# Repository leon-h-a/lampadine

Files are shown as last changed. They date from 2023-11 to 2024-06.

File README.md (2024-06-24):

### Connection between Arduino and PCB header
    ARD_13  -> 1
    ARD_12  -> 2
    ARD_11  -> 3
    ARD_10  -> 4
    ARD_GND -> 5

### Settings for programming via Arduino (platformio)
1. Install platformio on Windows
2. Init project ```pio project init --board attiny85``` ($ pio boards)
3. Install dependency ```pio lib install ADCTouch```
4. Setup Platformio to flash via Arduino (platformio.ini)

        [env:attiny85]
        platform = atmelavr
        board = attiny85
        framework = arduino
        upload_protocol = stk500v1
        lib_deps = martin2250/ADCTouch@^1.0.4
        upload_flags =
                -P$UPLOAD_PORT
                -b$UPLOAD_SPEED
        upload_port = COM7
        upload_speed = 19200

5. Flash with ```pio run --target upload```

### In case of avrdude verification error, mismatch byte

Remember to power PCB via USB-C before uploading.

### Timing issues

Define 'board_build.f_cpu' flag in platformio.ini conf file

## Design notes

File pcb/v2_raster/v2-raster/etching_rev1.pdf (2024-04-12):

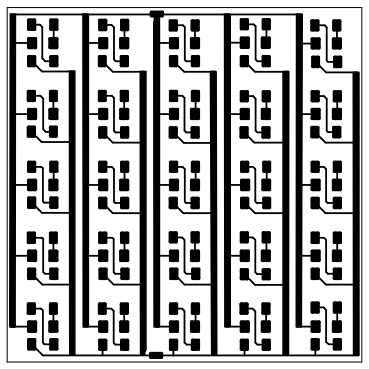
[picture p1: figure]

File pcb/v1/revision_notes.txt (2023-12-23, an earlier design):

V1:
Pogreske kod narucivanja:
2023-12-16 - Assembly V1
 - LED 		krivi footprint (narucene premale)
 - R13 		krivi footprint (naruceni premali)
 - LED10	povecati footprint u schemi
 - C3		krivi footprint (narucen premali)
 - C4		krivi footprint (narucen premali)
 - ARD		povecati footprint THT

Tocke revizije za verziju 2:
* Minimalni footprint za rucno lemljanje 1206(3216 metric)
* Bypass kondenzatore orijentirati jednako (C1 je 'naopacke')
* Drasticno povecati header prema Arduinu i povecati THT vije
* Povecati footprint LED diode koja signalizira napajanje uC-a
* Povecati PAD za External sens zicu
* Pronaci/napraviti footprint USB-C konektora sa THT konaktima (pwr-only)?
* Povecati footprint SRC CAP otpornika (?)

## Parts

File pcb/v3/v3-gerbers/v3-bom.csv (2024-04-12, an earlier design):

Comment | Designator | Footprint | LCSC Part Number
led | D11,D12,D3,D19,D20,D7,D22,D9,D18,D25,D23,D6,D1,D17,D5,D15,D21,D2,D16,D4,D10,D13,D24,D8,D14 | D_0603_1608Metric | C5160732
500 ohm | R19,R24,R22,R12,R6,R27,R20,R18,R11,R29,R10,R28,R25,R26,R16,R21,R7,R17,R14,R5,R23,R9,R15,R13,R8 | R_0603_1608Metric | C2828837
1uF | C1,C2 | C_0603_1608Metric | C1592
0.1uF | C3 | C_0603_1608Metric | C14663
10k | R4,R3 | R_0603_1608Metric | C15401
5k1 | R1,R2 | R_0603_1608Metric | C23186
4.7uF | C4 | C_0603_1608Metric | C1705

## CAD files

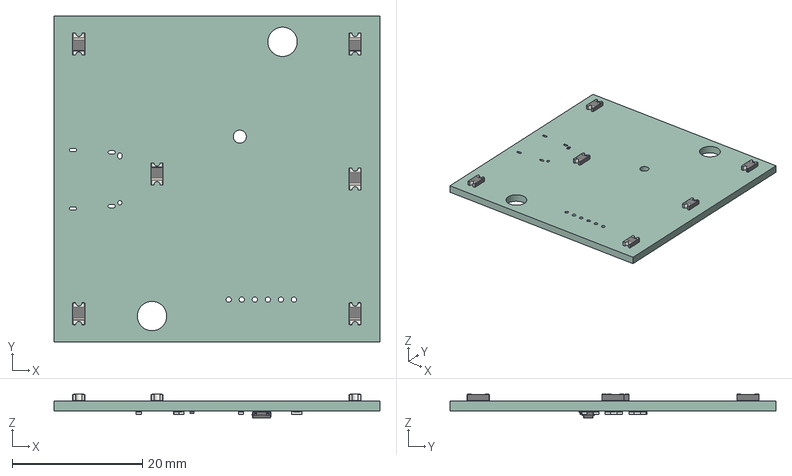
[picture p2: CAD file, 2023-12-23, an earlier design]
pcb/v1/export for inventor/v1-rev1/v1_rev1.step
50.0 x 50.0 x 3.61 mm
v1 PCB

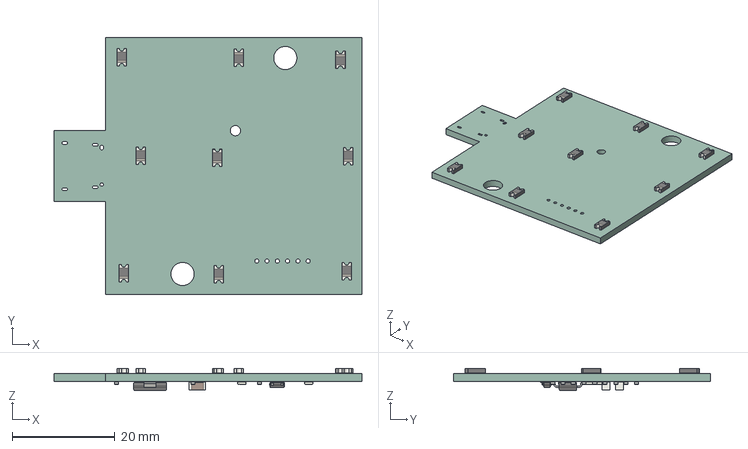
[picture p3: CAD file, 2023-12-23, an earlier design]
pcb/v1/export for inventor/v1-rev2/v1_rev2.step
60.0 x 50.0 x 4.36 mm
v1 PCB

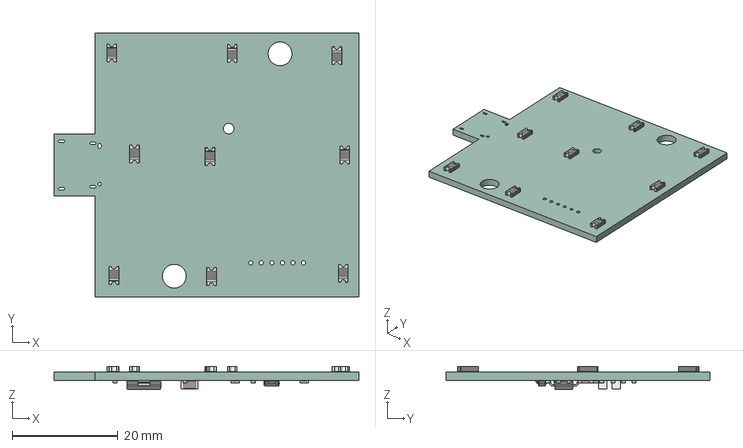
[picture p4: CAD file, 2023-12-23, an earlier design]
pcb/v1/export for inventor/v1-rev3/v1_rev3.step
57.7 x 50.0 x 4.36 mm
_autosave-v1 PCB

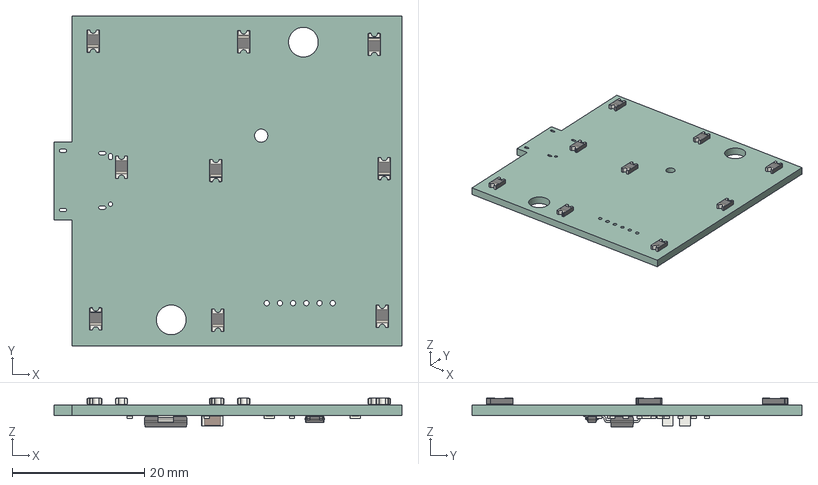
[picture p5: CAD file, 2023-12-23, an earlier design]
pcb/v1/export for inventor/v1-rev4/v1_rev4.step
52.7 x 50.0 x 4.36 mm
v1 PCB

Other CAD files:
pcb/v1/export for inventor/v1-rev1/C_0201_0603Metric.iam
pcb/v1/export for inventor/v1-rev1/D_1206_3216Metric.iam
pcb/v1/export for inventor/v1-rev1/OldVersions/v1_rev1.0003.iam
pcb/v1/export for inventor/v1-rev1/R_0603_1608Metric.iam
pcb/v1/export for inventor/v1-rev1/SOLID.ipt
pcb/v1/export for inventor/v1-rev1/SOLID_1.ipt
pcb/v1/export for inventor/v1-rev1/SOLID_2.ipt
pcb/v1/export for inventor/v1-rev1/SOLID_3.ipt
pcb/v1/export for inventor/v1-rev1/TSOT-23.iam
pcb/v1/export for inventor/v1-rev1/v1 PCB.ipt
pcb/v1/export for inventor/v1-rev1/v1_rev1.iam
pcb/v1/export for inventor/v1-rev2/C_1206_3216Metric.iam
pcb/v1/export for inventor/v1-rev2/D_1206_3216Metric.iam
pcb/v1/export for inventor/v1-rev2/OldVersions/v1_rev2_import.0002.iam
pcb/v1/export for inventor/v1-rev2/R_0603_1608Metric.iam
pcb/v1/export for inventor/v1-rev2/SOLID.ipt
pcb/v1/export for inventor/v1-rev2/SOLID_1.ipt
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

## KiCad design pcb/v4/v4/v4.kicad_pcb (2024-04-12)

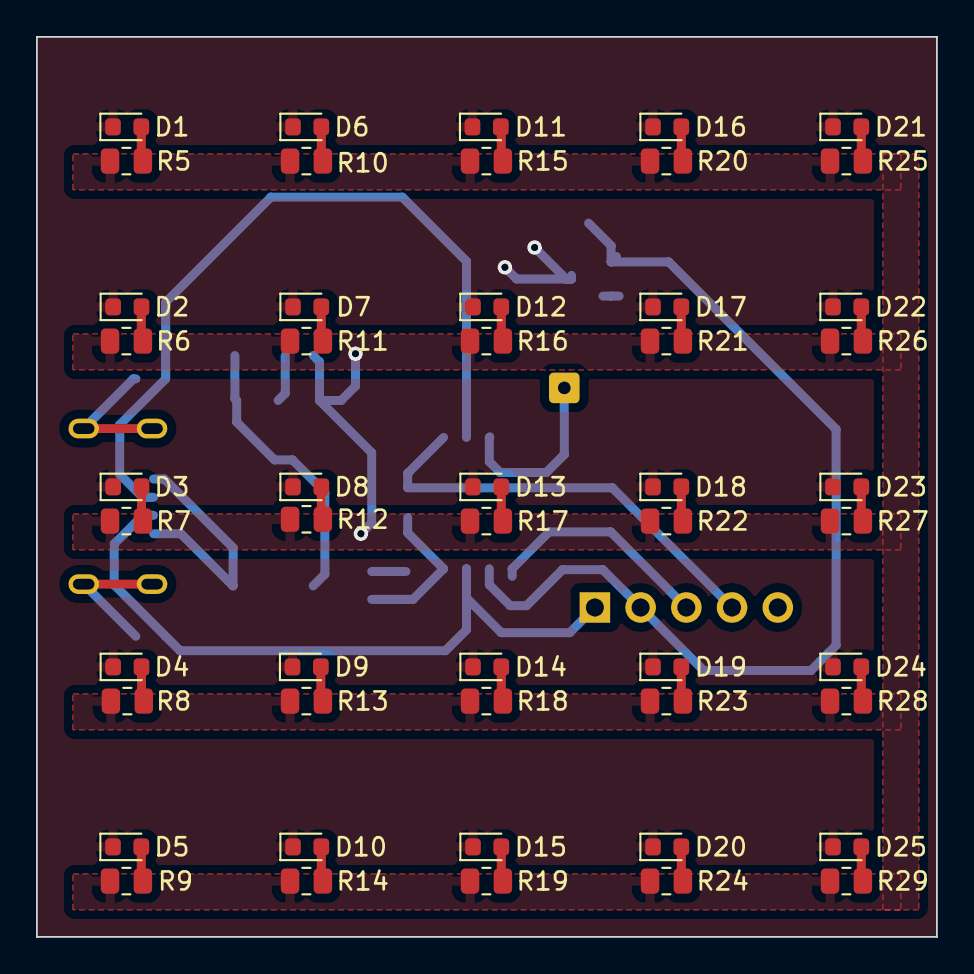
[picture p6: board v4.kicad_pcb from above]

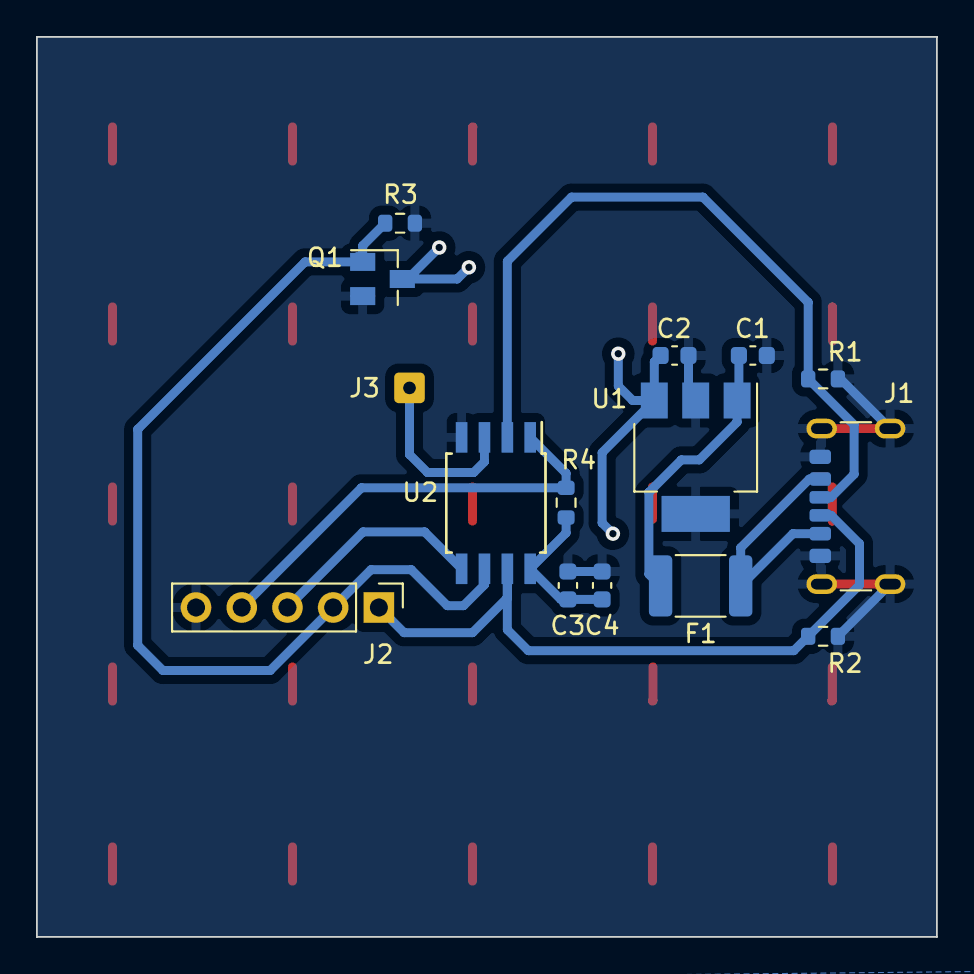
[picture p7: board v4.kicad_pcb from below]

Board: 2 copper layers, 50.0 x 50.0 mm, 65 parts (15 on the bottom side), 37 nets.

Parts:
C1, C2: 1uF; C_0603_1608Metric
C3: 0.1uF; C_0603_1608Metric
C4: 4.7uF; C_0603_1608Metric
D1, D2, D3, D4, D5, D6, D7, D8, D9, D10, D11, D12, D13, D14, D15, D16, D17, D18, D19, D20, D21, D22, D23, D24, D25: WHITE; D_0603_1608Metric
F1: Polyfuse; Fuse_1812_4532Metric_Pad1.30x3.40mm_HandSolder
J1: USB_C_Receptacle_PowerOnly_6P; USB_C_Receptacle_GCT_USB4125-xx-x-0190_6P_TopMnt_Horizontal
J2: Conn_01x05_Socket; PinHeader_1x05_P2.54mm_Vertical
J3: External Capacitance; SolderWire-0.15sqmm_1x01_D0.5mm_OD1.5mm
Q1: NMOS; SuperSOT-3
R1, R2: 5k1; R_0603_1608Metric
R3, R4: 10k; R_0603_1608Metric
R5, R6, R7, R8, R9, R10, R11, R12, R13, R14, R15, R16, R17, R18, R19, R20, R21, R22, R23, R24, R25, R26, R27, R28, R29: 500; R_0805_2012Metric
U1: MCP1703Ax-500xxDB; SOT-223-3_TabPin2
U2: ATtiny85-20S; SOIC-8W_5.3x5.3mm_P1.27mm

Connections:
CIRC_PWR: C2.1, R5.1, R6.1, R7.1, R8.1, R9.1, R10.1, R11.1, R12.1, R13.1, R14.1, R15.1, R16.1, R17.1, R18.1, R19.1, R20.1, R21.1, R22.1, R23.1, R24.1, R25.1, R26.1, R27.1, R28.1, R29.1, U1.3 (VO)
GND: C1.2, C2.2, C3.2, C4.2, J1.A12 (GND), J1.B12 (GND), J1.S1 (SHIELD), J2.5, Q1.2 (S), R1.2, R2.2, R3.2, U1.2 (GND), U2.4 (GND)
IC_PS: C3.1, C4.1, R4.2, U2.8 (VCC)
LED_CTRL: J2.2, Q1.1 (G), R3.1, U2.6 (PB1)
LED_OUT: D1.1 (K), D2.1 (K), D3.1 (K), D4.1 (K), D5.1 (K), D6.1 (K), D7.1 (K), D8.1 (K), D9.1 (K), D10.1 (K), D11.1 (K), D12.1 (K), D13.1 (K), D14.1 (K), D15.1 (K), D16.1 (K), D17.1 (K), D18.1 (K), D19.1 (K), D20.1 (K), D21.1 (K), D22.1 (K), D23.1 (K), D24.1 (K), D25.1 (K), Q1.3 (D)
unnamed: D1.2 (A), R5.2
unnamed: D2.2 (A), R6.2
unnamed: D3.2 (A), R7.2
unnamed: D4.2 (A), R8.2
unnamed: D5.2 (A), R9.2
unnamed: D6.2 (A), R10.2
unnamed: D7.2 (A), R11.2
unnamed: D8.2 (A), R12.2
unnamed: D9.2 (A), R13.2
unnamed: D10.2 (A), R14.2
unnamed: D11.2 (A), R15.2
unnamed: D12.2 (A), R16.2
unnamed: D13.2 (A), R17.2
unnamed: D14.2 (A), R18.2
unnamed: D15.2 (A), R19.2
unnamed: D16.2 (A), R20.2
unnamed: D17.2 (A), R21.2
unnamed: D18.2 (A), R22.2
unnamed: D19.2 (A), R23.2
unnamed: D20.2 (A), R24.2
unnamed: D21.2 (A), R25.2
unnamed: D22.2 (A), R26.2
unnamed: D23.2 (A), R27.2
unnamed: D24.2 (A), R28.2
unnamed: D25.2 (A), R29.2
unnamed: F1.1, J1.A9 (VBUS), J1.B9 (VBUS)
unnamed: J2.3, U2.5 (AREF/PB0)
unnamed: J2.4, R4.1, U2.1 (~RESET/PB5)
SRC_CAP1: J1.A5 (CC1), J2.1, R2.1, U2.7 (PB2)
SRC_CAP2: J1.B5 (CC2), R1.1, U2.2 (XTAL1/PB3)
TOUCH_SENS_EXT: J3.1, U2.3 (XTAL2/PB4)
USB_PWR: C1.1, F1.2, U1.1 (VI)

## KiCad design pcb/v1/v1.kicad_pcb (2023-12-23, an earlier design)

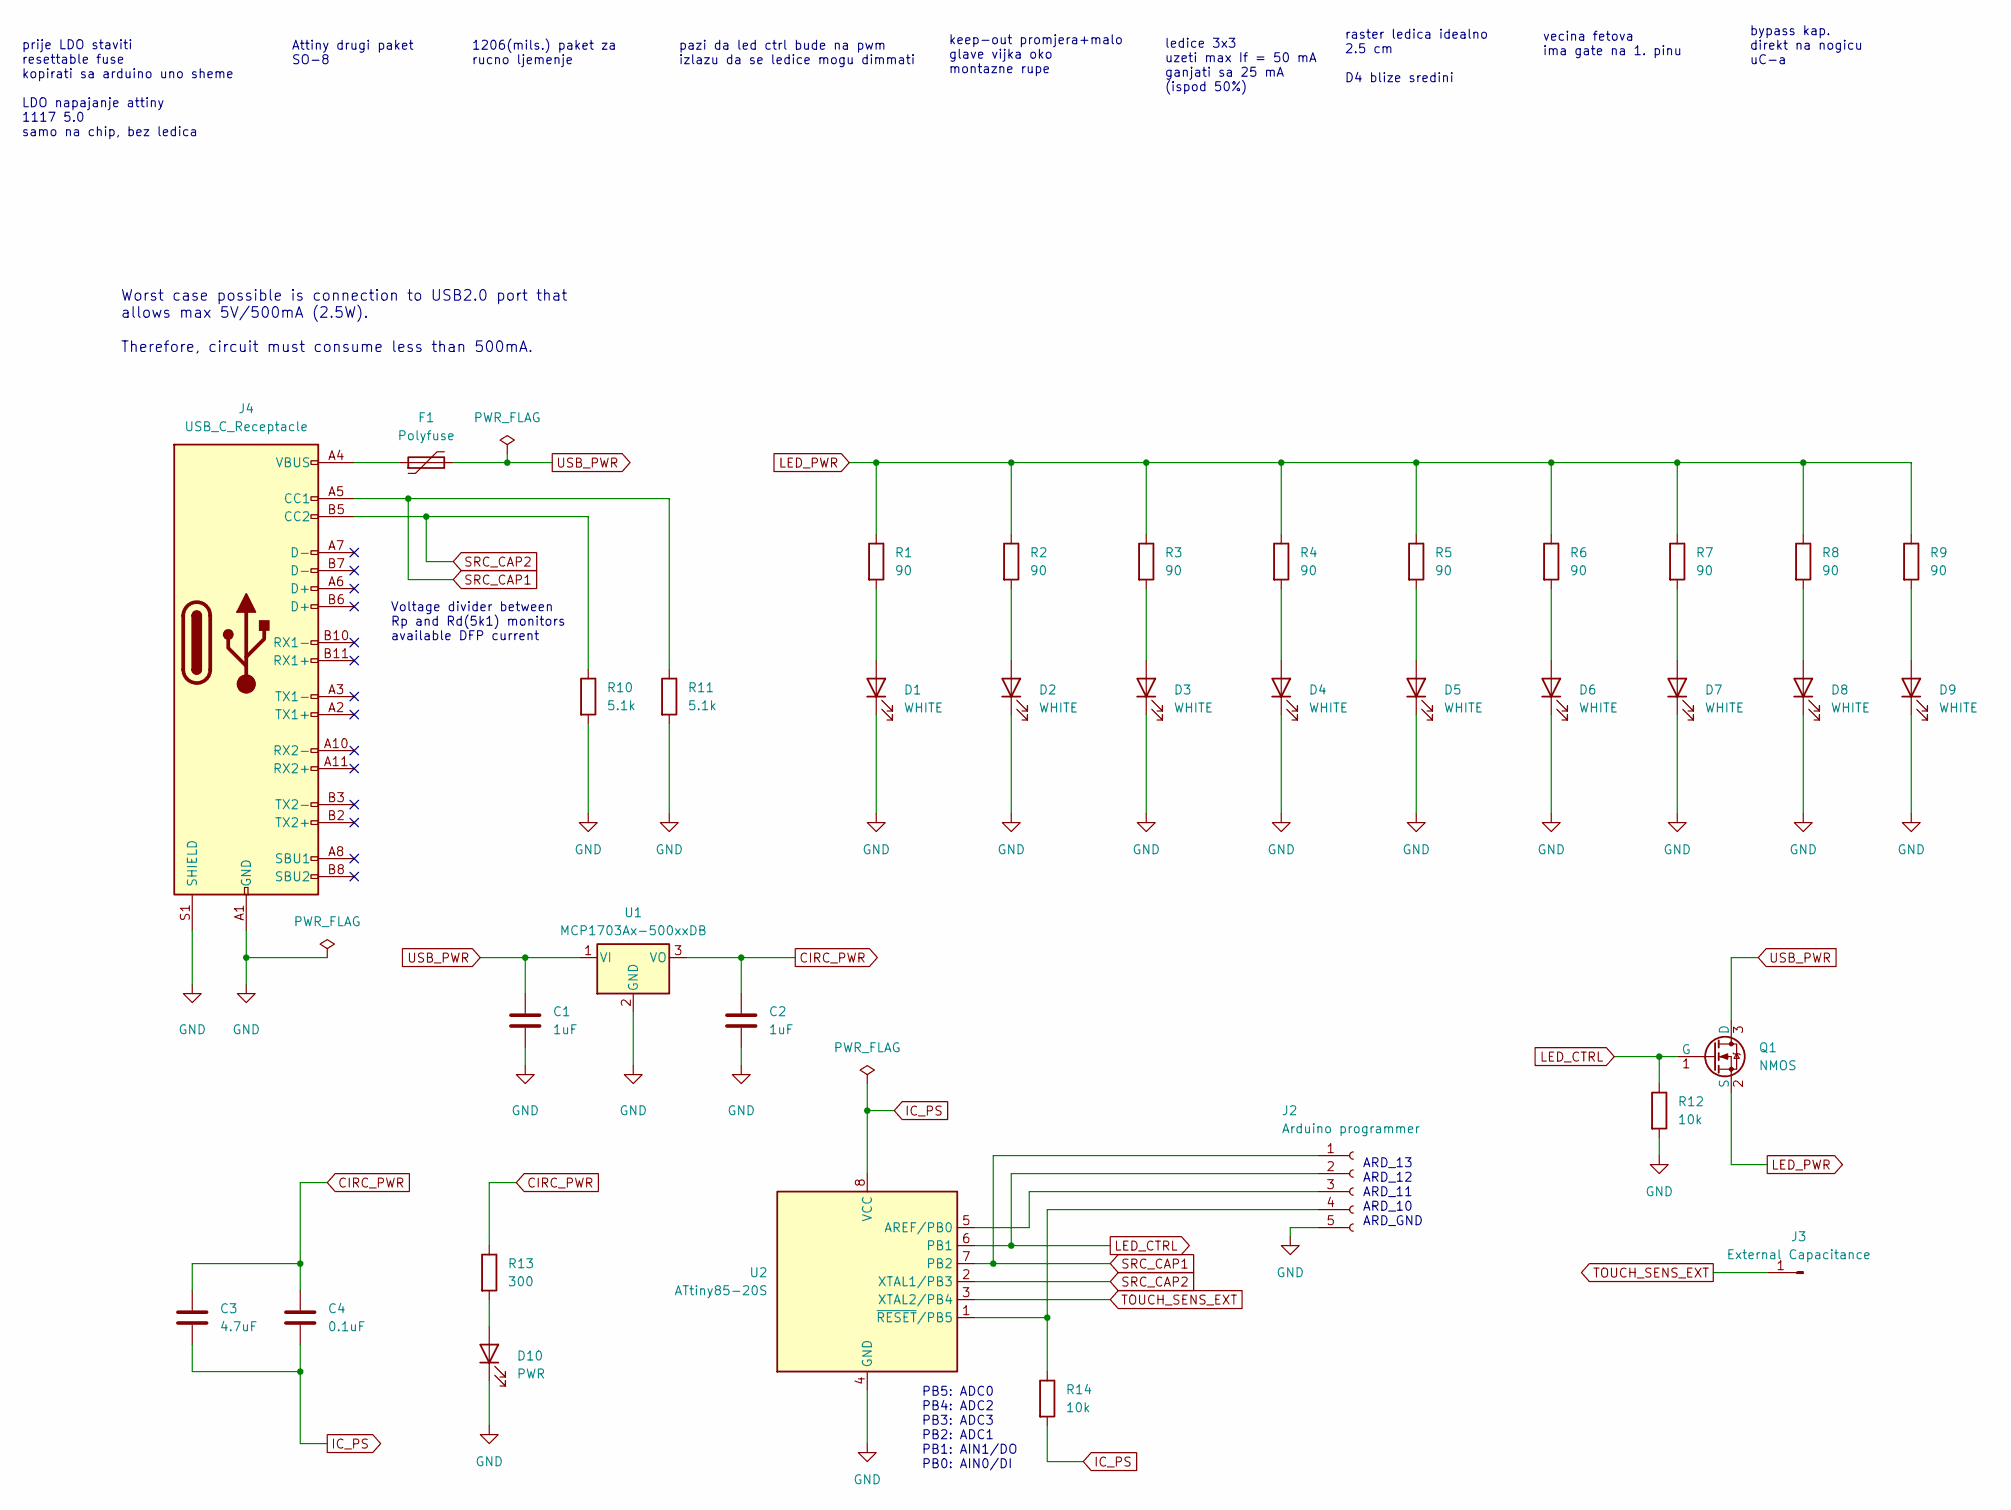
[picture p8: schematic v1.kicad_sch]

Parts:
C1, C2: 1uF; C_1206_3216Metric_Pad1.33x1.80mm_HandSolder
C3: 4.7uF; C_1206_3216Metric_Pad1.33x1.80mm_HandSolder
C4: 0.1uF; C_1206_3216Metric_Pad1.33x1.80mm_HandSolder
D1, D2, D3, D4, D5, D6, D7, D8, D9: WHITE; D_1206_3216Metric_Pad1.42x1.75mm_HandSolder
D10: PWR; D_0201_0603Metric_Pad0.64x0.40mm_HandSolder
F1: Polyfuse; Fuse_1812_4532Metric_Pad1.30x3.40mm_HandSolder
J2: Arduino programmer; PinHeader_1x05_P1.00mm_Horizontal
J3: External Capacitance; SolderWirePad_1x01_SMD_1x2mm
J4: USB_C_Receptacle; USB_C_Receptacle_Amphenol_12401610E4-2A
Q1: NMOS; SuperSOT-3
R1, R2, R3, R4, R5, R6, R7, R8, R9: 90; R_0603_1608Metric_Pad0.98x0.95mm_HandSolder
R10, R11: 5.1k; R_0603_1608Metric_Pad0.98x0.95mm_HandSolder
R12, R14: 10k; R_0603_1608Metric_Pad0.98x0.95mm_HandSolder
R13: 300; R_0603_1608Metric_Pad0.98x0.95mm_HandSolder
U1: MCP1703Ax-500xxDB; SOT-223-3_TabPin2
U2: ATtiny85-20S; SOIC-8W_5.3x5.3mm_P1.27mm

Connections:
CIRC_PWR: C2.1, C3.1, C4.1, R13.1, U1.3 (VO)
GND: C1.2, C2.2, D1.1 (K), D2.1 (K), D3.1 (K), D4.1 (K), D5.1 (K), D6.1 (K), D7.1 (K), D8.1 (K), D9.1 (K), D10.1 (K), J2.5, J4.A1 (GND), J4.A12 (GND), J4.B1 (GND), J4.B12 (GND), J4.S1 (SHIELD), R10.2, R11.2, R12.2, U1.2 (GND), U2.4 (GND)
IC_PS: C3.2, C4.2, R14.2, U2.8 (VCC)
LED_CTRL: J2.2, Q1.1 (G), R12.1, U2.6 (PB1)
LED_PWR: Q1.2 (S), R1.1, R2.1, R3.1, R4.1, R5.1, R6.1, R7.1, R8.1, R9.1
unnamed: D1.2 (A), R1.2
unnamed: D2.2 (A), R2.2
unnamed: D3.2 (A), R3.2
unnamed: D4.2 (A), R4.2
unnamed: D5.2 (A), R5.2
unnamed: D6.2 (A), R6.2
unnamed: D7.2 (A), R7.2
unnamed: D8.2 (A), R8.2
unnamed: D9.2 (A), R9.2
unnamed: D10.2 (A), R13.2
unnamed: F1.1, J4.A4 (VBUS), J4.A9 (VBUS), J4.B4 (VBUS), J4.B9 (VBUS)
unnamed: J2.3, U2.5 (AREF/PB0)
unnamed: J2.4, R14.1, U2.1 (~RESET/PB5)
SRC_CAP1: J2.1, J4.A5 (CC1), R11.1, U2.7 (PB2)
SRC_CAP2: J4.B5 (CC2), R10.1, U2.2 (XTAL1/PB3)
TOUCH_SENS_EXT: J3.1, U2.3 (XTAL2/PB4)
USB_PWR: C1.1, F1.2, Q1.3 (D), U1.1 (VI)

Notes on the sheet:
ARD_13 ARD_12 ARD_11 ARD_10 ARD_GND
ledice 3x3 uzeti max If = 50 mA ganjati sa 25 mA (ispod 50%)
vecina fetova ima gate na 1. pinu
pazi da led ctrl bude na pwm izlazu da se ledice mogu dimmati
raster ledica idealno 2.5 cm D4 blize sredini
bypass kap. direkt na nogicu uC-a
keep-out promjera+malo glave vijka oko montazne rupe
1206(mils.) paket za rucno ljemenje
Voltage divider between Rp and Rd(5k1) monitors available DFP current
PB5: ADC0 PB4: ADC2 PB3: ADC3 PB2: ADC1 PB1: AIN1/DO PB0: AIN0/DI
prije LDO staviti resettable fuse kopirati sa arduino uno sheme LDO napajanje attiny 1117 5.0 samo na chip, bez ledica
Worst case possible is connection to USB2.0 port that allows max 5V/500mA (2.5W). Therefore, circuit must consume less than 500mA.
Attiny drugi paket SO-8

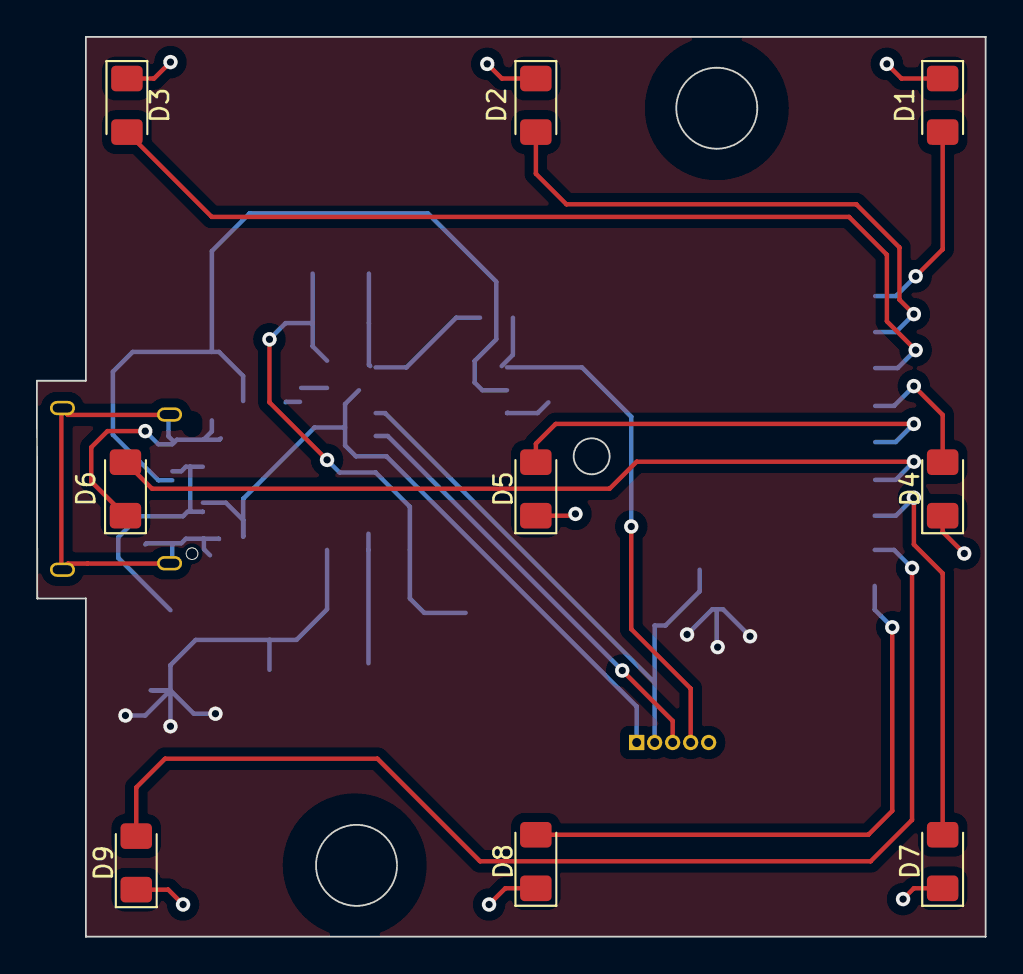
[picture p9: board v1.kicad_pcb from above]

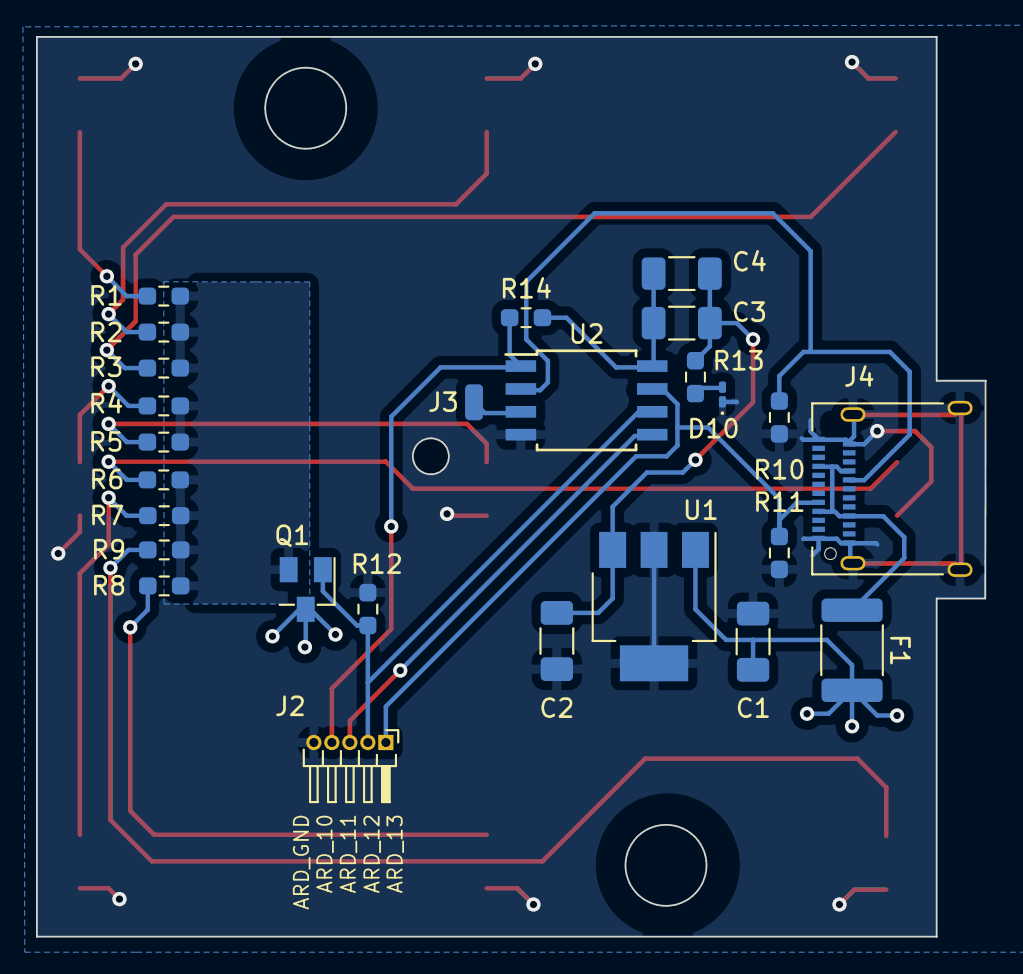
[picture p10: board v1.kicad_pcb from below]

Board: 2 copper layers, 52.7 x 50.0 mm, 35 parts (26 on the bottom side), 22 nets.

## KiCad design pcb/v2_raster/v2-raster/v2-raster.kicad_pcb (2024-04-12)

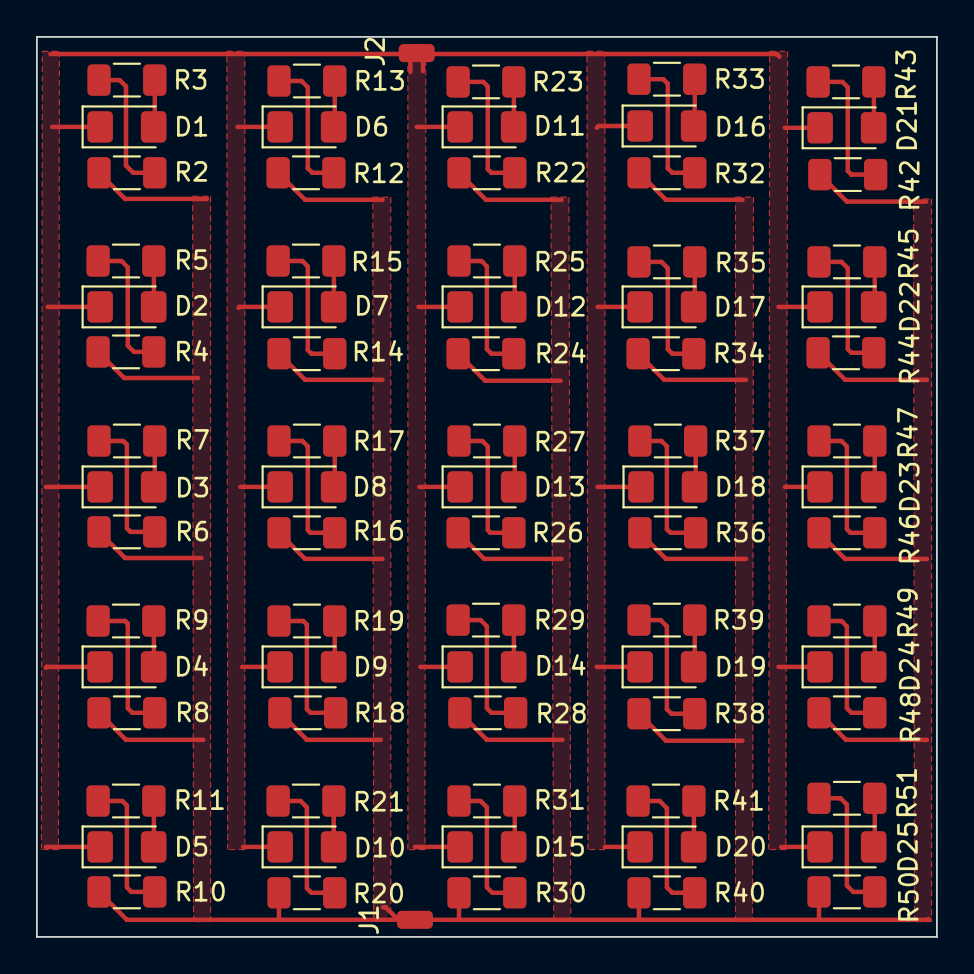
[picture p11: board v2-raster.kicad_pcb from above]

Board: 2 copper layers, 50.0 x 50.0 mm, 77 parts (0 on the bottom side), 52 nets.

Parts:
D1, D2, D3, D4, D5, D6, D7, D8, D9, D10, D11, D12, D13, D14, D15, D16, D17, D18, D19, D20, D21, D22, D23, D24, D25: LED; D_1206_3216Metric_Pad1.42x1.75mm_HandSolder
J1, J2: Conn_01x01_Pin; SolderWirePad_1x01_SMD_1x2mm
R2, R4, R6, R8, R10, R12, R14, R16, R18, R20, R22, R24, R26, R28, R30, R32, R34, R36, R38, R40, R42, R44, R46, R48, R50: 0; R_1206_3216Metric_Pad1.30x1.75mm_HandSolder
R3, R5, R7, R9, R11, R13, R15, R17, R19, R21, R23, R25, R27, R29, R31, R33, R35, R37, R39, R41, R43, R45, R47, R49, R51: 500; R_1206_3216Metric_Pad1.30x1.75mm_HandSolder

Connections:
+5V: J1.1, R2.1, R4.1, R6.1, R8.1, R10.1, R12.1, R14.1, R16.1, R18.1, R20.1, R22.1, R24.1, R26.1, R28.1, R30.1, R32.1, R34.1, R36.1, R38.1, R40.1, R42.1, R44.1, R46.1, R48.1, R50.1
GND: D1.1 (K), D2.1 (K), D3.1 (K), D4.1 (K), D5.1 (K), D6.1 (K), D7.1 (K), D8.1 (K), D9.1 (K), D10.1 (K), D11.1 (K), D12.1 (K), D13.1 (K), D14.1 (K), D15.1 (K), D16.1 (K), D17.1 (K), D18.1 (K), D19.1 (K), D20.1 (K), D21.1 (K), D22.1 (K), D23.1 (K), D24.1 (K), D25.1 (K), J2.1
unnamed: D1.2 (A), R3.2
unnamed: D2.2 (A), R5.2
unnamed: D3.2 (A), R7.2
unnamed: D4.2 (A), R9.2
unnamed: D5.2 (A), R11.2
unnamed: D6.2 (A), R13.2
unnamed: D7.2 (A), R15.2
unnamed: D8.2 (A), R17.2
unnamed: D9.2 (A), R19.2
unnamed: D10.2 (A), R21.2
unnamed: D11.2 (A), R23.2
unnamed: D12.2 (A), R25.2
unnamed: D13.2 (A), R27.2
unnamed: D14.2 (A), R29.2
unnamed: D15.2 (A), R31.2
unnamed: D16.2 (A), R33.2
unnamed: D17.2 (A), R35.2
unnamed: D18.2 (A), R37.2
unnamed: D19.2 (A), R39.2
unnamed: D20.2 (A), R41.2
unnamed: D21.2 (A), R43.2
unnamed: D22.2 (A), R45.2
unnamed: D23.2 (A), R47.2
unnamed: D24.2 (A), R49.2
unnamed: D25.2 (A), R51.2
unnamed: R2.2, R3.1
unnamed: R4.2, R5.1
unnamed: R6.2, R7.1
unnamed: R8.2, R9.1
unnamed: R10.2, R11.1
unnamed: R12.2, R13.1
unnamed: R14.2, R15.1
unnamed: R16.2, R17.1
unnamed: R18.2, R19.1
unnamed: R20.2, R21.1
unnamed: R22.2, R23.1
unnamed: R24.2, R25.1
unnamed: R26.2, R27.1
unnamed: R28.2, R29.1
unnamed: R30.2, R31.1
unnamed: R32.2, R33.1
unnamed: R34.2, R35.1
unnamed: R36.2, R37.1
unnamed: R38.2, R39.1
unnamed: R40.2, R41.1
unnamed: R42.2, R43.1
unnamed: R44.2, R45.1
unnamed: R46.2, R47.1
unnamed: R48.2, R49.1
unnamed: R50.2, R51.1

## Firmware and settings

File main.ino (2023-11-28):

#include <ADCTouch.h>

int ref;
int led_state = 0;
int brightness = 0;
int init_flag = 0;
int up_flag = 0;
int down_flag = 0;

int rampDelay = 4;
int holdCheckTimeout = 100;
int toggleThr = 250;


void setup() 
{
    pinMode(1, OUTPUT);
    ref = ADCTouch.read(A3, 500);    // sense pin uC#3
}

int rampUp(){  // Return True if ramp exited and False if rampDown should be called
  int hold = ADCTouch.read(A3);
  hold -= ref;

  // Here will be edge cases when user touched but this
  // func was called. Test gracefull exit by mimicking
  // user touch.
  if (hold < toggleThr){
    led_state = 1;
    return 1;
  }

  up_flag = 1;
  down_flag = 0;

  if (brightness > 240){
    // End of ramp, call rampDown in main
    led_state = 1;
    return 0;
  }
  else {
    brightness += 5;
    analogWrite(1, brightness);
    }
  delay(rampDelay);
};

int rampDown(){  // Return True if ramp exited and False if rampUp should be called
  while (1){
    int hold = ADCTouch.read(A3);
    hold -= ref;

    if (hold < toggleThr){
      led_state = 1;
      return 1;
    }

    up_flag = 0;
    down_flag = 1;

    if (brightness < 10) {
      // End of ramp, call rampUp from main
      led_state = 0;
      return 0;
    }
    else {
      brightness -= 5;
      analogWrite(1, brightness);
    }
    delay(rampDelay); 
  }
};

void loop() 
{
    int touch = ADCTouch.read(A3);
    touch -= ref;

    // User pressed sens
    if (touch > toggleThr) {  // Raw ADC value
      
      // Turn on lamp to full power only on first sens-ON after HW reset
      if (init_flag == 0){
        init_flag = 1;
        analogWrite(1, 255);
        led_state = 1;
        brightness = 255;
      }

      else {
        // Define delay as something that is not visible
        // But enough to differentiate between touch/hold
        delay(holdCheckTimeout);
  
        int hold = ADCTouch.read(A3);
        hold -= ref;
  
        if (hold > toggleThr) {  // Raw ADC value
          // Cap sens active after delay -> User hold
          if (brightness > 125){
            int status = rampDown();
          }
          else {
           int status = rampUp(); 
          }
        }
  
        else {
          // Cap sense not active -> User touch
          if (led_state == 0){
            analogWrite(1, brightness);
            led_state = 1;
          }
          else {
            analogWrite(1, 0);
            led_state = 0;
          }
        }
      }
    }
    
    delay(5);
}

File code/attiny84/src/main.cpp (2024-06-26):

#include <ADCTouch.h>

int ref;
int ledPin = 1;
int toggleThr = 250;

void setup() {
    ref = ADCTouch.read(A2, 500);    // sense pin uC#3
    pinMode(ledPin, OUTPUT);  // sets the pin as output
}


void loop() {
    int hold = ADCTouch.read(A2);
    hold -= ref;

    if (hold > toggleThr) {
        analogWrite(ledPin, 255); 
    }
    else {
        analogWrite(ledPin, 0); 
    }
}

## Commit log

2023-11-28 feat(cap touch): single ADC, working on Arduino
2023-11-28 feat(attiny85): cap input/DO LED working
2023-12-23 feat(pcb): added V1 files with revision notes for V2
    [C_0201_0603Metric.iam, C_1206_3216Metric.iam, D_1206_3216Metric.iam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]
2024-04-12 refactor: project structure
    [C_0201_0603Metric.iam, C_1206_3216Metric.iam, D_1206_3216Metric.iam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]
2024-04-12 fix(pcb): files from OD
    [C_0201_0603Metric.iam, C_1206_3216Metric.iam, D_1206_3216Metric.iam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]
2024-04-12 feat(pcb): add v4
    * LEDs moved from Source to Drain branch of MOSFET
    * Bypass capacitors on Attiny series to parallel connection
    [leds.kicad_sch, v4.kicad_pcb, v4.kicad_sch]
2024-04-12 feat(code): attiny FW update via Arduino Uno
2024-06-26 feat(v4): ADC in and LED out working
